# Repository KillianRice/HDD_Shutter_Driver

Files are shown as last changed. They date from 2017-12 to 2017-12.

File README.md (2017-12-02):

# HDD_Shutter_Driver #

HDD shutter driver circuit based on Rob Scholten's 2007 RSI paper (see below). Modifications include the option of using an IXYS IXDF604PI (about $2/IC) instead of the TI LMD18200 (about $17/IC) to drive the shutter. 

## Notes ##
- Outputs are to standard BNC connectors so care should be taken to avoid shorting to ground. 
- H3 (PWR_SEL) allows using a single voltage supply to power the IC and provide current for the shutter. 
- H1 and H2 allow the selection of the output polarity (OUT_1x when using the IXDF604PI, OUT_2x when using LMD18200). 

## Ordering ##
### Shutter Driver ###
The main circuit for driving HDD shutters. 

- v1.1: <a href="https://oshpark.com/shared_projects/gJmzOIRQ">Shutter Driver Rev. 1.1 (OSH Park)</a>

- v1.0: <a href="https://oshpark.com/shared_projects/CgeGIYMU">Shutter Driver Rev. 1.0 (OSH Park)</a>

### Power Distribution ###
Circuit used to breakout a power supply for multiple shutter driver boards. 
- v1.1: **Add notes**
- v1.0: <a href="https://oshpark.com/shared_projects/fE8gVI9B">Positive Power Distribution Rev. 1.0 (OSH Park)</a>

## Original paper ## 
Enhanced laser shutter using a hard disk drive rotary voice-coil actuator

R. E. Scholten

Review of Scientific Instruments <b>78</b>, 026101 (2007)

https://doi.org/10.1063/1.2437199

## Also see ##
- <a href="https://github.com/JQIamo/hard-drive-shutter">JQI's hard-drive-shutter</a>

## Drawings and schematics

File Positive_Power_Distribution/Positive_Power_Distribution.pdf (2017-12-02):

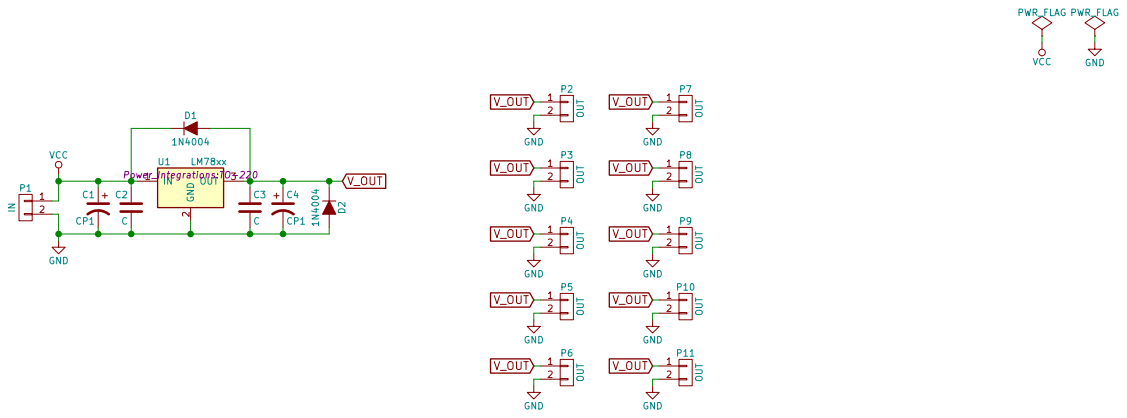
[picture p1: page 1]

File: Positive_Power_Distribution.sch Sheet: / Rice University

Id: 1/1 Title: Positive Power Distribution

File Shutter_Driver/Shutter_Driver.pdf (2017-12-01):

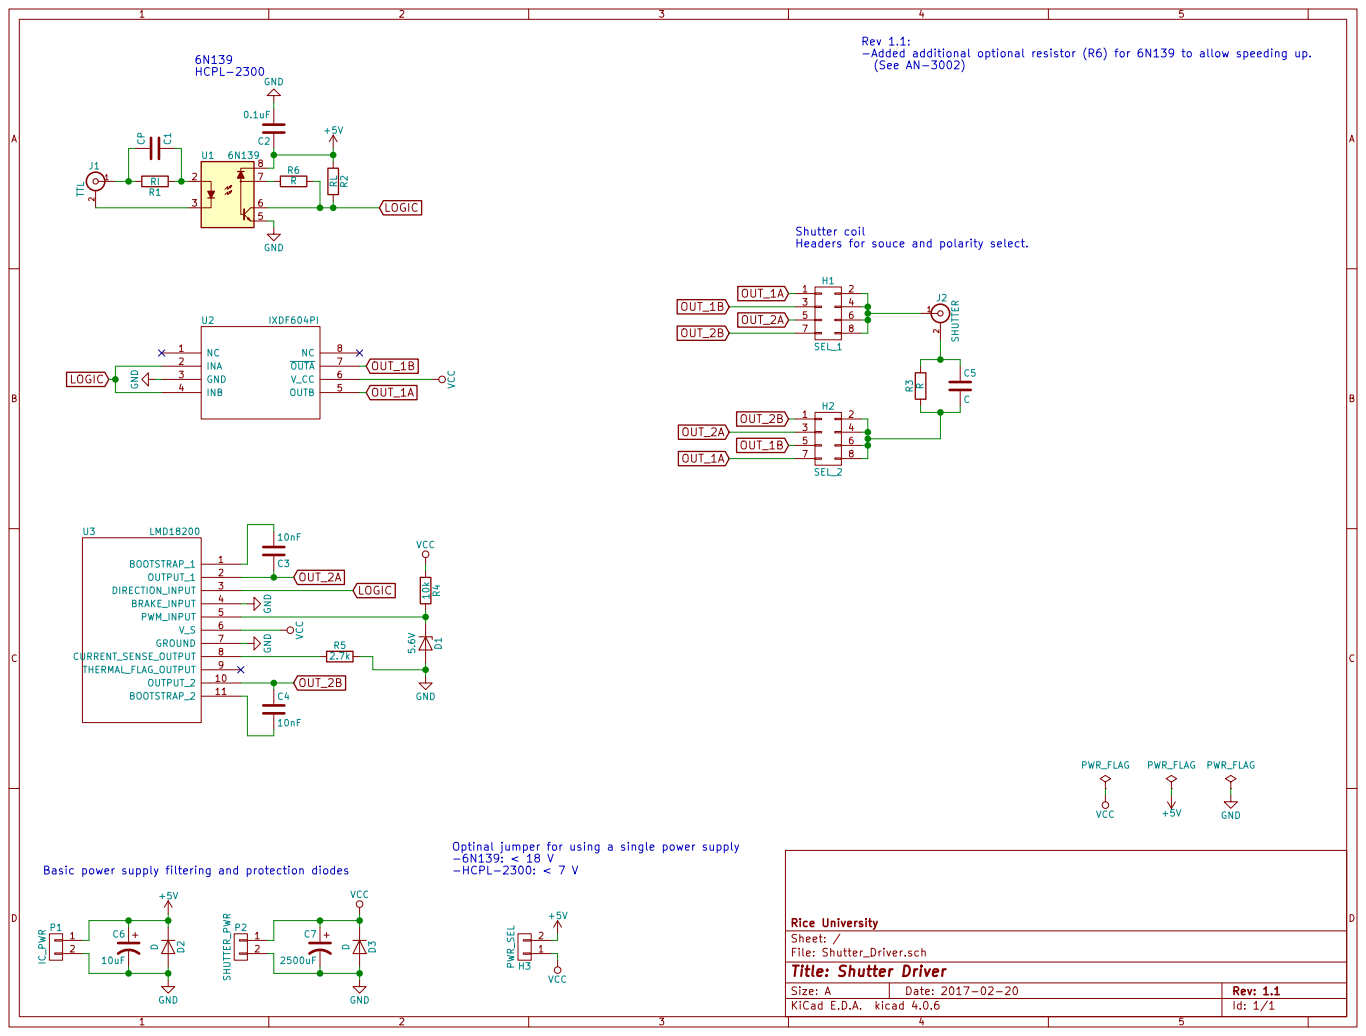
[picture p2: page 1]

Shutter coil
Headers for souce and polarity select.

VCC Optinal jumper for using a single power supply
-HCPL-2300: < 7 V

Basic power supply filtering and protection diodes

File: Shutter_Driver.sch Sheet: / Rice University

Id: 1/1 Title: Shutter Driver

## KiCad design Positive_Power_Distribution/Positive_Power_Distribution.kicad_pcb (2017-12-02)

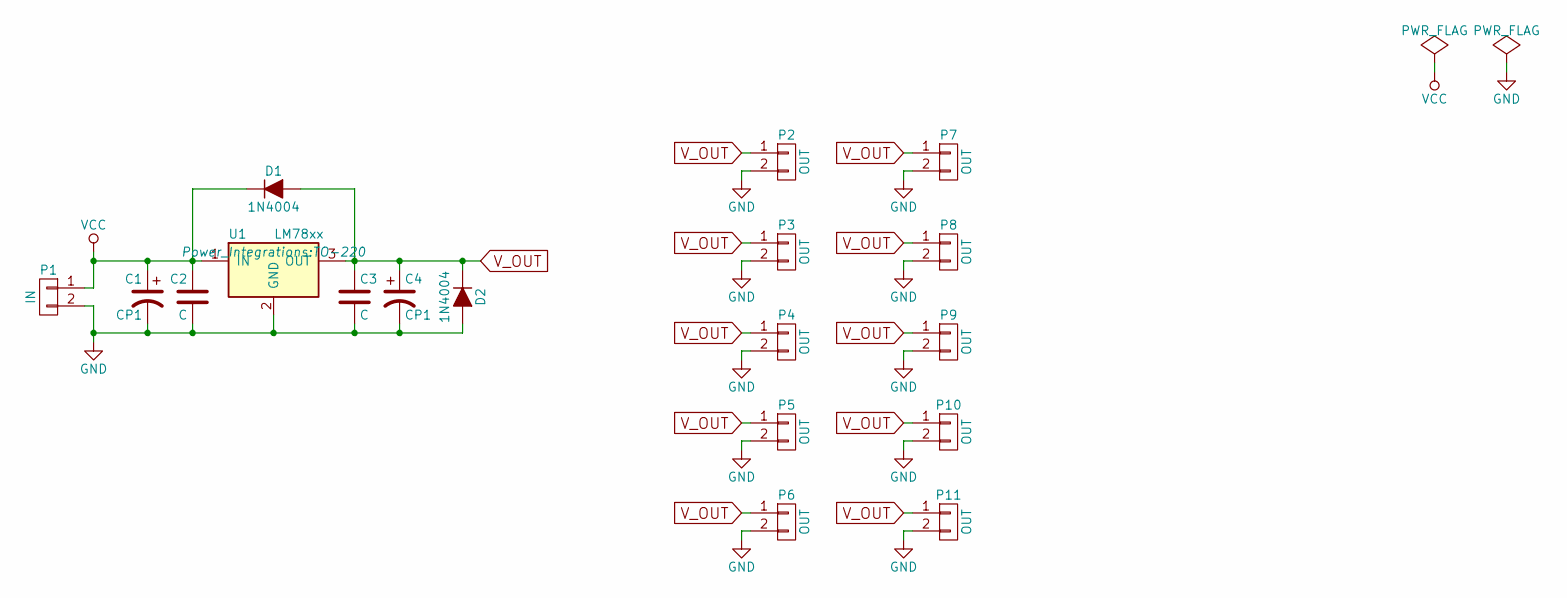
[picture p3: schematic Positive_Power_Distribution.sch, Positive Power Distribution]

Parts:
C1: CP1; CP_Radial_D10.0mm_P5.00mm
C2, C3: C; C_Disc_D5.0mm_W2.5mm_P5.00mm
C4: CP1; CP_Radial_D5.0mm_P2.00mm
D1, D2: 1N4004; D_DO-41_SOD81_P10.16mm_Horizontal
P1: IN; Socket_MOLEX-KK-RM2-54mm_Lock_2pin_straight
P2, P3, P4, P5, P6, P7, P8, P9, P10, P11: OUT; Socket_MOLEX-KK-RM2-54mm_Lock_2pin_straight
U1: LM78xx; TO-220

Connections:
GND: C1.2, C2.2, C3.2, C4.2, D2.2 (A), P1.2, P2.2, P3.2, P4.2, P5.2, P6.2, P7.2, P8.2, P9.2, P10.2, P11.2, U1.2 (GND)
VCC: C1.1, C2.1, D1.1 (K), P1.1, U1.1 (IN)
V_OUT: C3.1, C4.1, D1.2 (A), D2.1 (K), P2.1, P3.1, P4.1, P5.1, P6.1, P7.1, P8.1, P9.1, P10.1, P11.1, U1.3 (OUT)

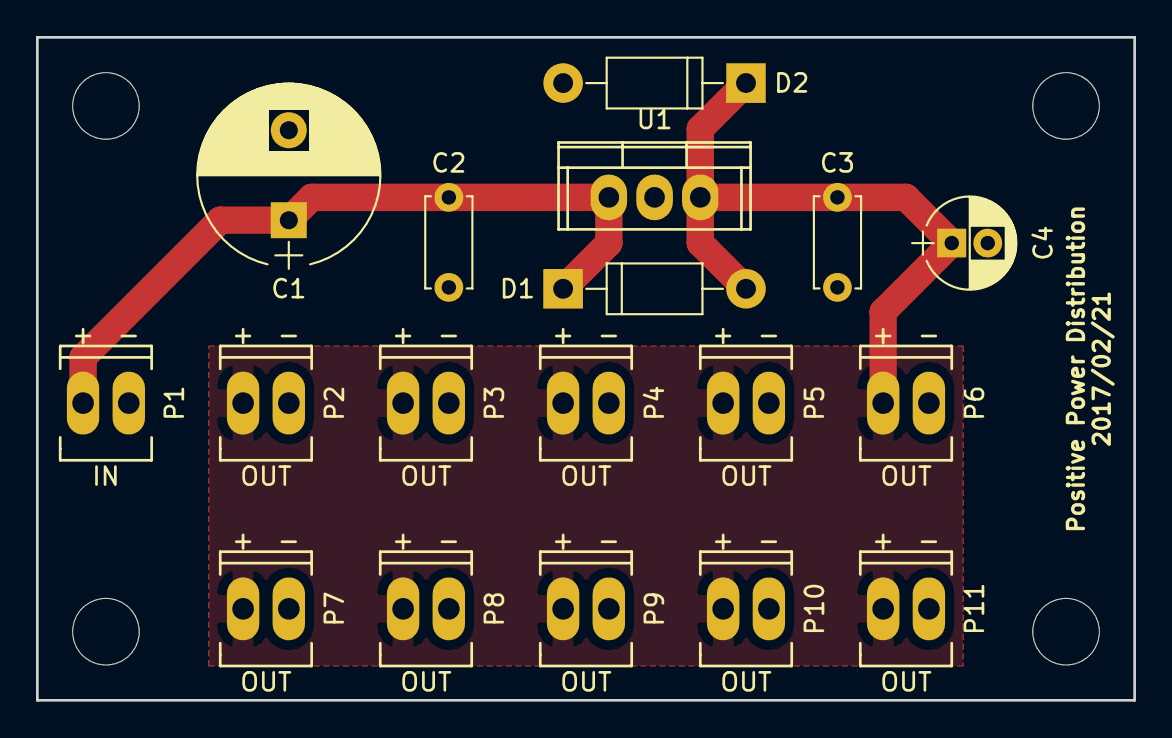
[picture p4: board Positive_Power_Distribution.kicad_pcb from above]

Board: 2 copper layers, 61.0 x 36.8 mm, 18 parts (0 on the bottom side), 3 nets.

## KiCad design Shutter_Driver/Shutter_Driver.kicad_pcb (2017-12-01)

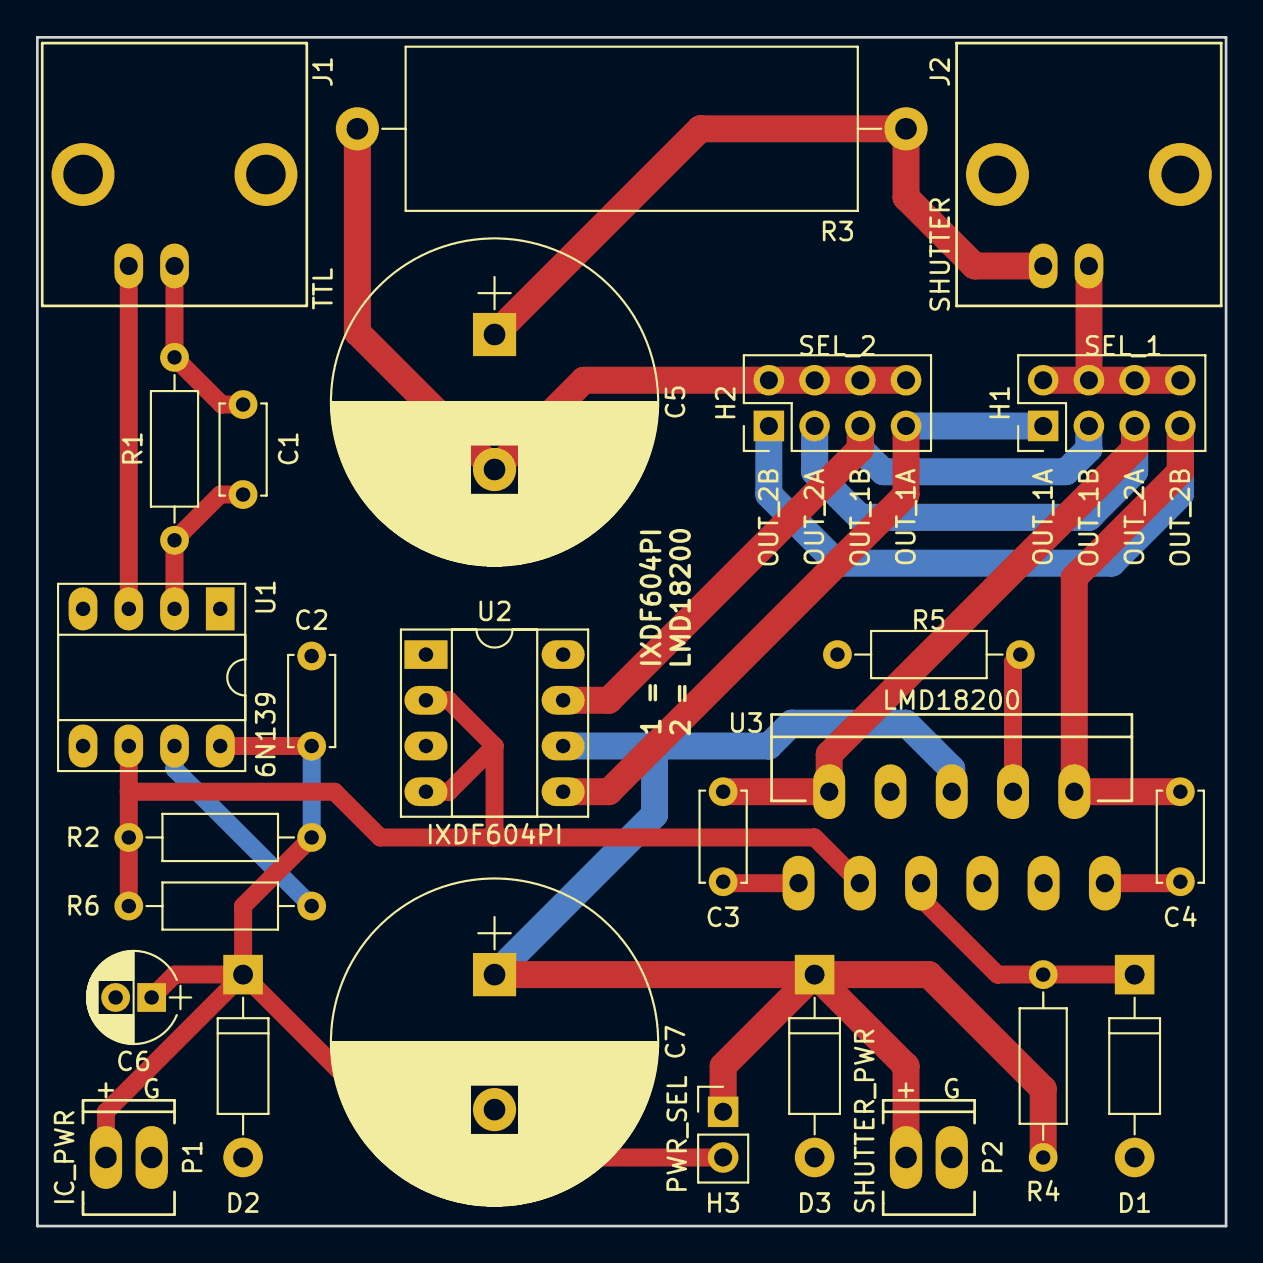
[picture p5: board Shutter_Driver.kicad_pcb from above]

Board: 2 copper layers, 66.0 x 66.0 mm, 26 parts (0 on the bottom side), 19 nets.

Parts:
C1: CP; C_Disc_D5.0mm_W2.5mm_P5.00mm
C2: 0.1uF; C_Disc_D5.0mm_W2.5mm_P5.00mm
C3, C4: 10nF; C_Disc_D5.0mm_W2.5mm_P5.00mm
C5: C; CP_Radial_D18.0mm_P7.50mm
C6: 10uF; CP_Radial_D5.0mm_P2.00mm
C7: 2500uF; CP_Radial_D18.0mm_P7.50mm
D1: 5.6V; D_DO-41_SOD81_P10.16mm_Horizontal
D2, D3: D; D_DO-41_SOD81_P10.16mm_Horizontal
H1: SEL_1; Pin_Header_Straight_2x04_Pitch2.54mm
H2: SEL_2; Pin_Header_Straight_2x04_Pitch2.54mm
H3: PWR_SEL; Pin_Header_Straight_1x02_Pitch2.54mm
J1: TTL; BNC_Socket_TYCO-AMP_LargePads
J2: SHUTTER; BNC_Socket_TYCO-AMP_LargePads
P1: IC_PWR; Socket_MOLEX-KK-RM2-54mm_Lock_2pin_straight
P2: SHUTTER_PWR; Socket_MOLEX-KK-RM2-54mm_Lock_2pin_straight
R1: RI; R_Axial_DIN0207_L6.3mm_D2.5mm_P10.16mm_Horizontal
R2: RL; R_Axial_DIN0207_L6.3mm_D2.5mm_P10.16mm_Horizontal
R3: R; R_Axial_Power_L25.0mm_W9.0mm_P30.48mm
R4: 10k; R_Axial_DIN0207_L6.3mm_D2.5mm_P10.16mm_Horizontal
R5: 2.7k; R_Axial_DIN0207_L6.3mm_D2.5mm_P10.16mm_Horizontal
R6: R; R_Axial_DIN0207_L6.3mm_D2.5mm_P10.16mm_Horizontal
U1: 6N139; DIP-8_W7.62mm_Socket_LongPads
U2: IXDF604PI; DIP-8_W7.62mm_Socket_LongPads
U3: LMD18200; Multiwatt_15_Vertical

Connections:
+5V: C2.1, C6.1, D2.1, H3.2, P1.1, R2.2, U1.8
GND: C2.2, C6.2, C7.2, D1.2, D2.2, D3.2, P1.2, P2.2, R5.2, U1.5, U2.3, U3.4, U3.7
LOGIC: R2.1, R6.2, U1.6, U2.2, U2.4, U3.3
unnamed: C1.1, R1.1, U1.2
unnamed: C1.2, J1.1, R1.2
unnamed: C3.2, U3.1
unnamed: C4.2, U3.11
unnamed: C5.1, J2.2, R3.2
unnamed: C5.2, H2.2, H2.4, H2.6, H2.8, R3.1
unnamed: D1.1, R4.1, U3.5
unnamed: H1.2, H1.4, H1.6, H1.8, J2.1
unnamed: J1.2, U1.3
unnamed: R5.1, U3.8
unnamed: R6.1, U1.7
OUT_1A: H1.1, H2.7, U2.5
OUT_1B: H1.3, H2.5, U2.7
OUT_2A: C3.1, H1.5, H2.3, U3.2
OUT_2B: C4.1, H1.7, H2.1, U3.10
VCC: C7.1, D3.1, H3.1, P2.1, R4.2, U2.6, U3.6

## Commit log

2017-12-01 Updated .gitignore for KiCad files
2017-12-01 Added KiCad files
    [Shutter_Driver.kicad_pcb, Shutter_Driver.sch]
2017-12-02 Added Shutter_Driver schematic PDF
2017-12-02 Added Positive_Power_Distribution circuit
    This circuit is used to breakout the power connections for multiple shutter drivers.
    [Positive_Power_Distribution.kicad_pcb, Positive_Power_Distribution.sch]
2018-02-11 Add files via upload
    Uploaded Gerber files.
    [Positive_Power_Distribution-B.Cu.gbl, Positive_Power_Distribution-B.Mask.gbs, Positive_Power_Distribution-B.SilkS.gbo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]
2018-02-11 Add files via upload
    Separated PTH (plated through holes) and NPTH (non-plated through holes) in .drl file.
    [Positive_Power_Distribution-B.Cu.gbl, Positive_Power_Distribution-B.Mask.gbs, Positive_Power_Distribution-B.SilkS.gbo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]
2018-02-11 Added Gerber and drill files.
    Drill file has PTH and NPTH separated into two .drl files.
    [Shutter_Driver-B.Cu.gbl, Shutter_Driver-B.Mask.gbs, Shutter_Driver-B.SilkS.gbo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]
